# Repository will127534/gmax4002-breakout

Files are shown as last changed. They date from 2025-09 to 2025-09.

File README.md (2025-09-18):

# GMAX4002 breakout board
A basic minimum GMAX4002 (1/1.7" 2048x1200 Global shutter) breakout board for Raspberry Pi



In general this is a simple breakout board for GMAX4002 sensor, see [here](https://github.com/will127534/gmax4002-v4l2-driver) on the driver side of things.
The caveat is that you will need to supply trigger pulses to the TEXP test point in order to trigger a new frame from the sensor and the board will not generate that signal for you, as such this is not really a complete board in my opinion but it might be easier for those who are taking this to integrate in their project.  

_DSC9919  
_DSC0018  
_DSC0022-2  
See the action in video here: [Youtube](https://youtu.be/cdhxaaCYhbM).  
Note that the decoupling capacitor requirements from the leaked pre-released datasheet is a bit... over spec in my opinion(There is no F-way you need 2 x 22uF, 10uF and 100nF for each pixel voltage regulator), the board is deisgned following the datasheet but you can see in the board photos I've omitted some of the capacitors when soldering and it work just fine (I guess).  

At the very least this board has been tested on RPI5 with analog discovery 2 as pulse generating source. Currently I have no plan to continuing develop this board as a raspberry pi camera module but it might be useful for someone looking at this sensor also. Lastly, this project is released as MIT license, do what ever you want with that.

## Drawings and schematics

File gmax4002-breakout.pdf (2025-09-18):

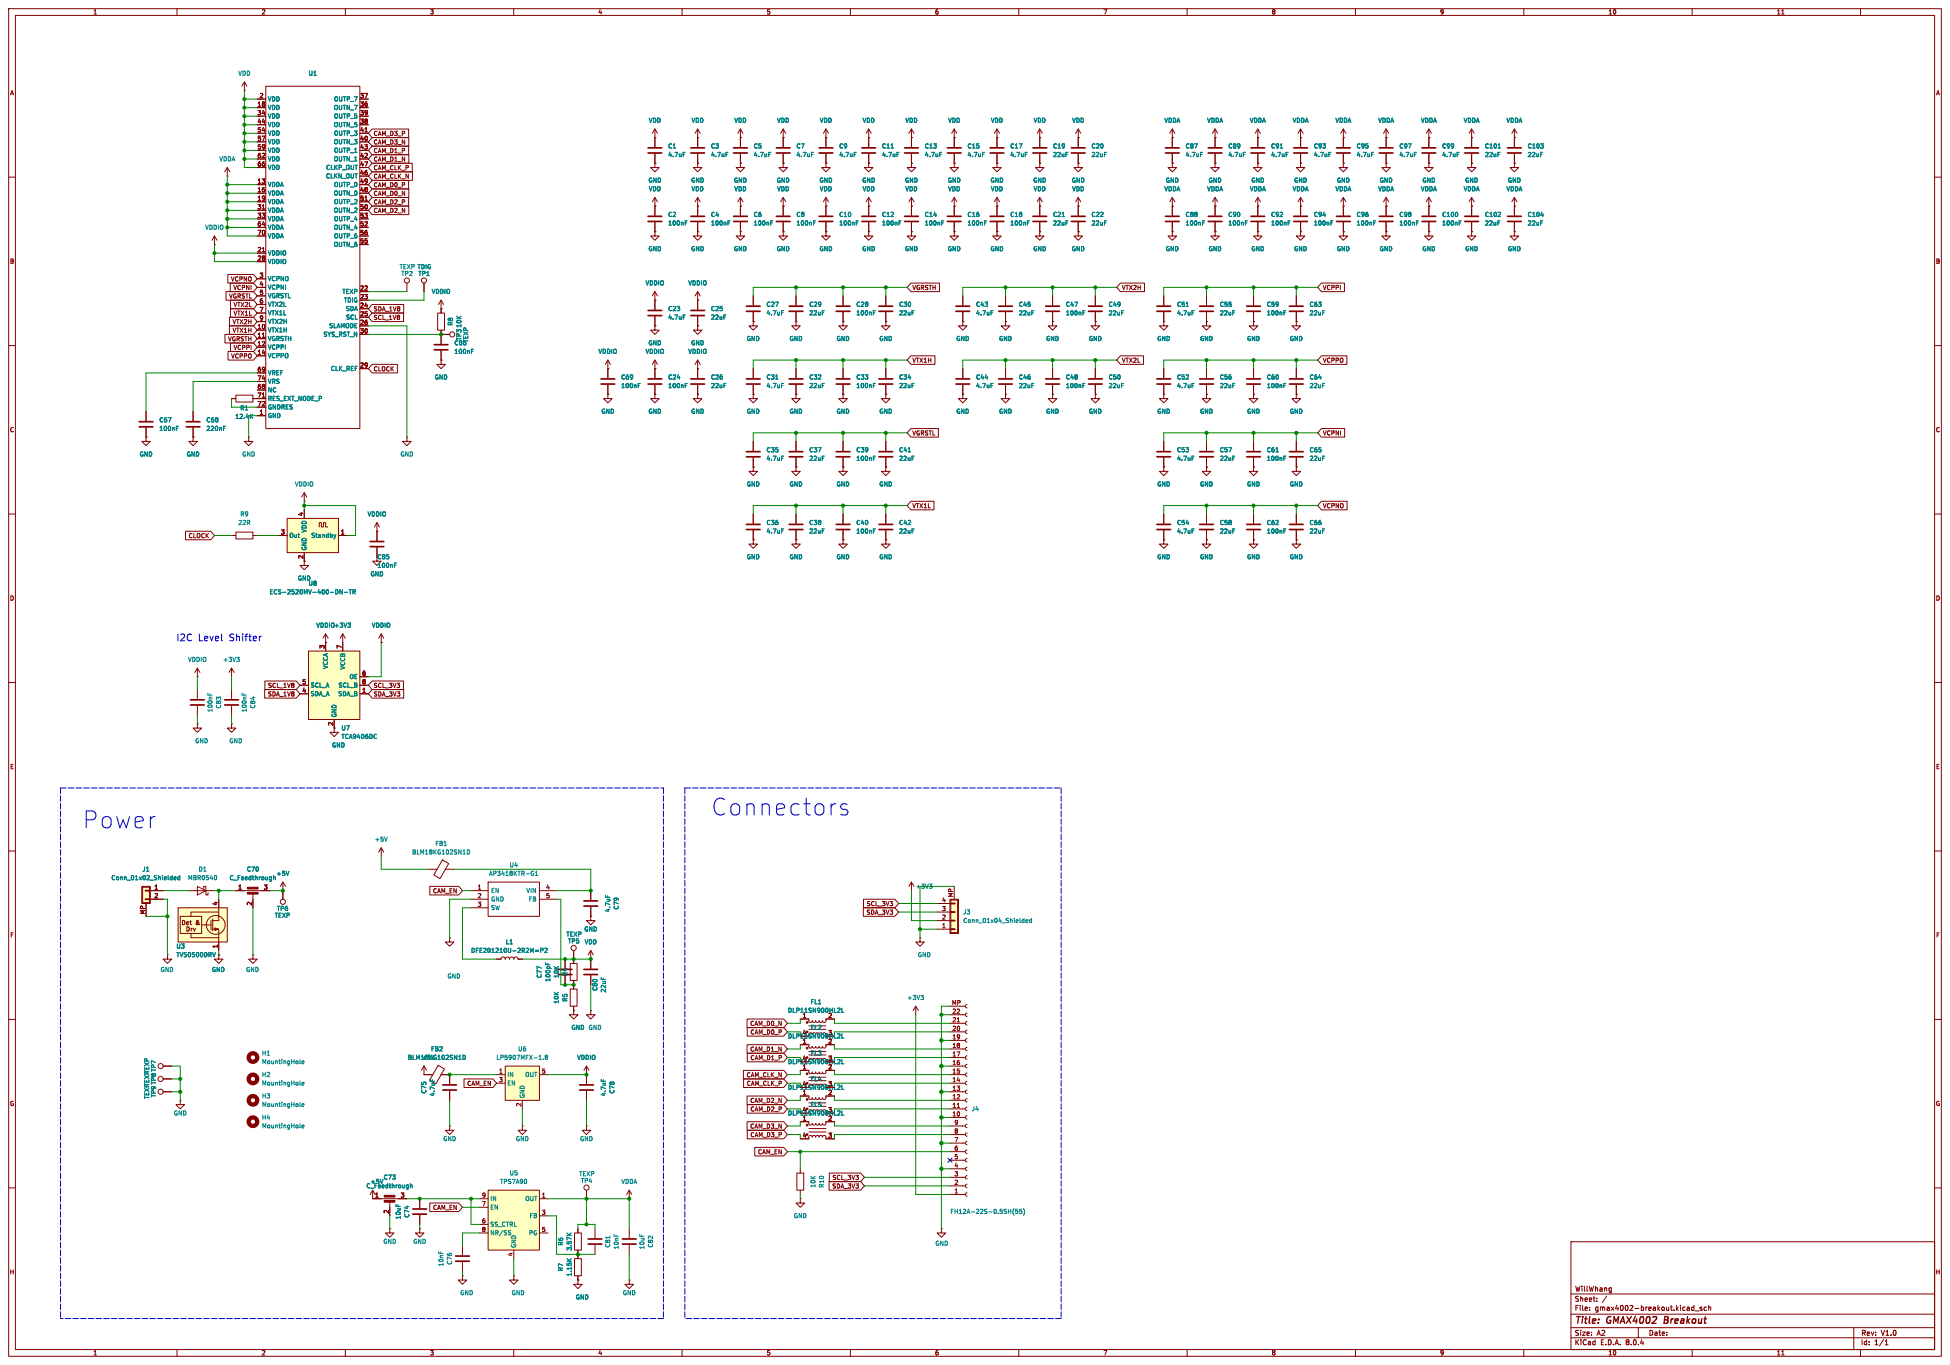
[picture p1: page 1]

4 PG 5 SS_CTRL 6 EN 7 NR/SS 8

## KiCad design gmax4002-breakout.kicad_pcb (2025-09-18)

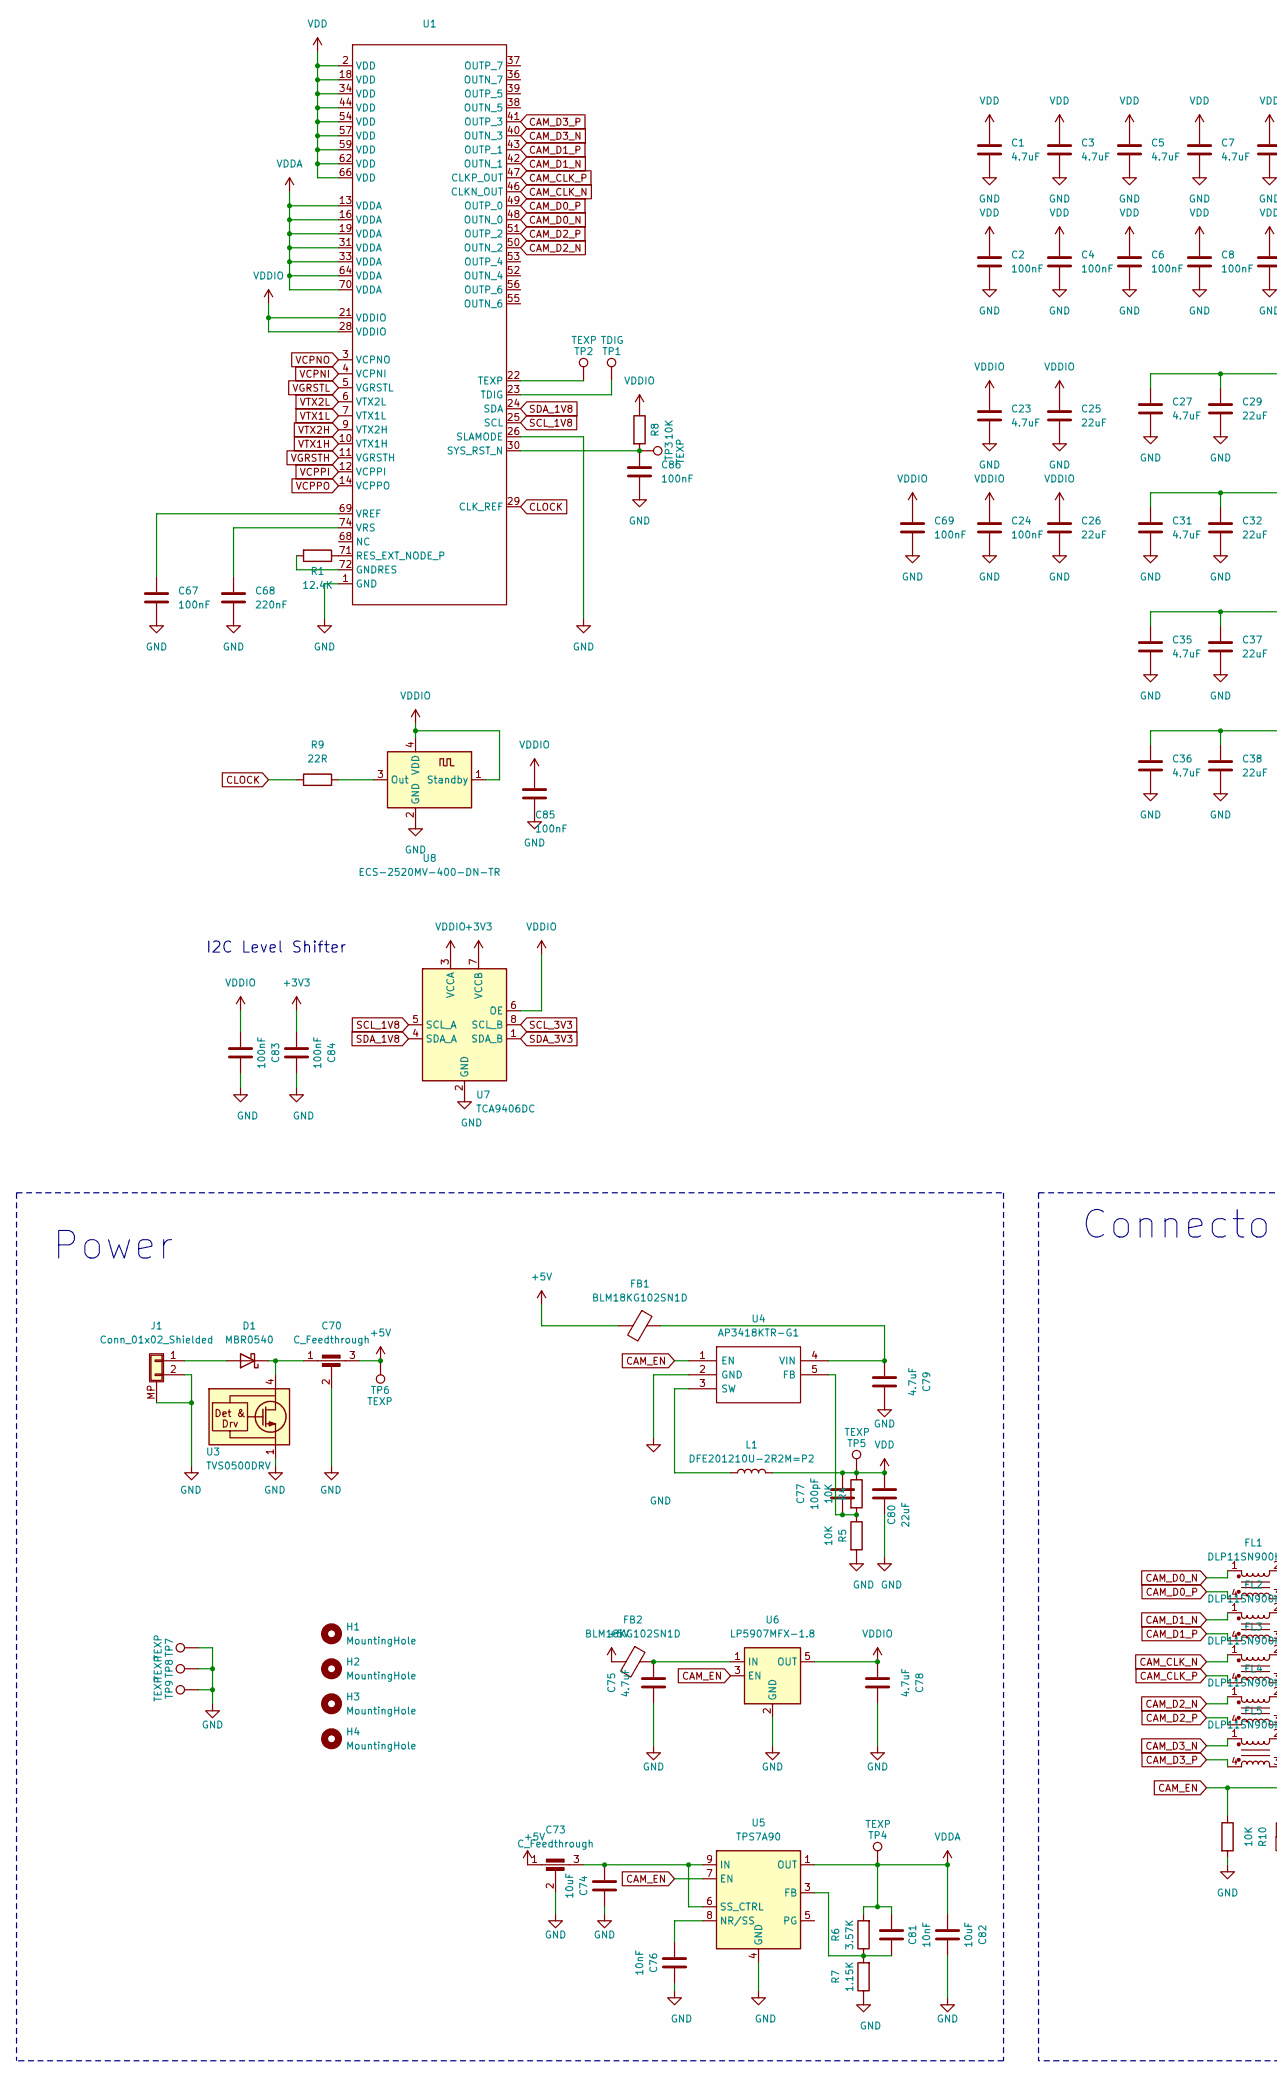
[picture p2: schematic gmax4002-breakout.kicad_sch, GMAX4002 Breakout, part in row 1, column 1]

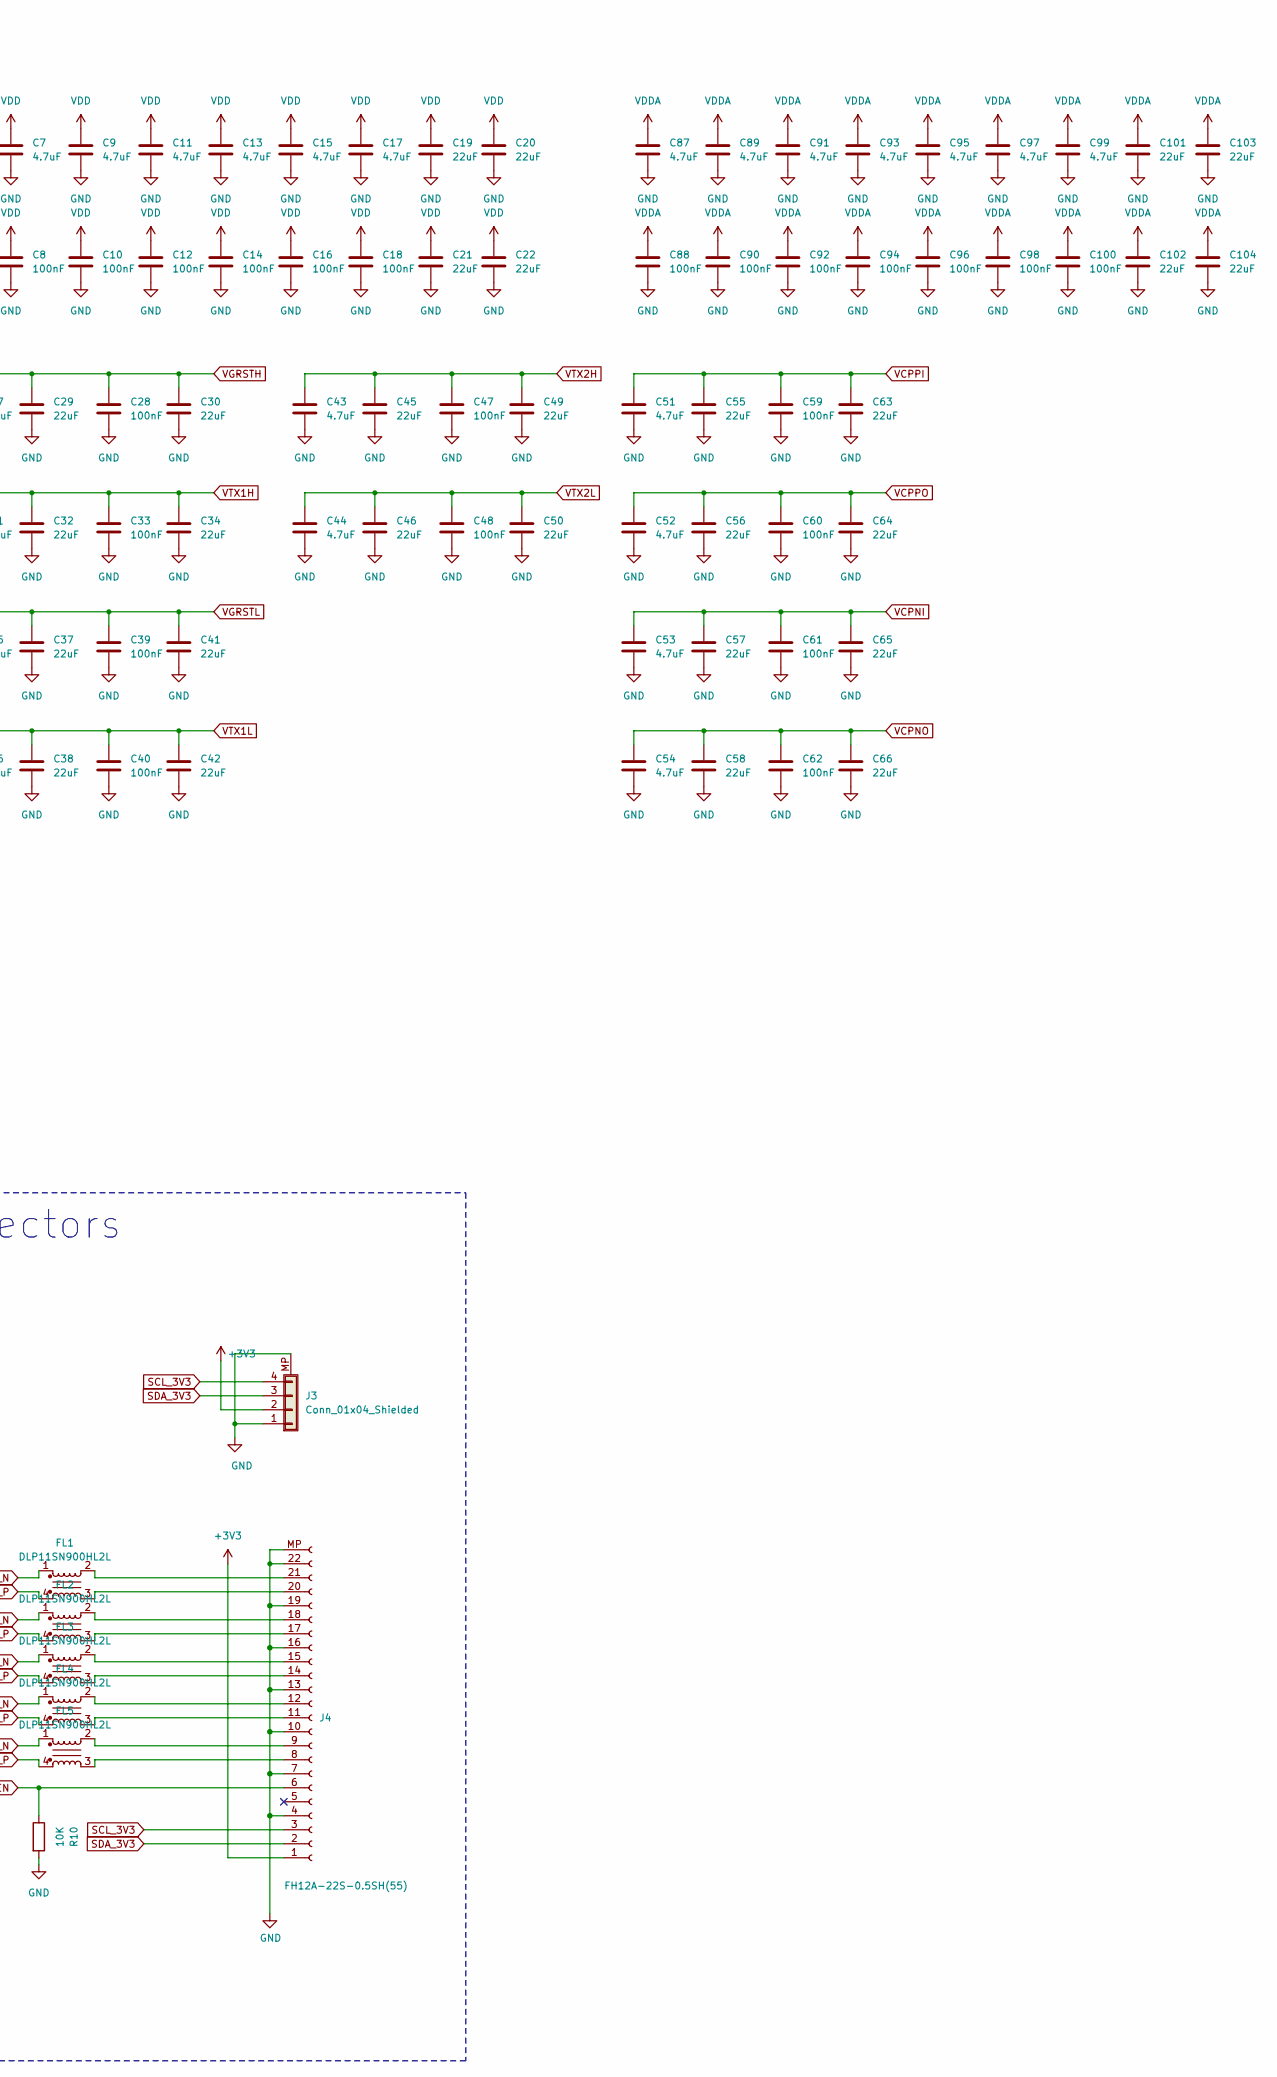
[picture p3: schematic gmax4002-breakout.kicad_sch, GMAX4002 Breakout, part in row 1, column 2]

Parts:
C1, C3, C5, C7, C9, C11, C13, C15, C17, C23, C27, C31, C35, C36, C43, C44, C51, C52, C53, C54, C87, C89, C91, C93, C95, C97, C99: 4.7uF; C_0402_1005Metric
C2, C4, C6, C8, C10, C12, C14, C16, C18, C24, C28, C33, C39, C40, C47, C48, C59, C60, C61, C62, C67, C69, C83, C84, C85, C86, C88, C90, C92, C94, C96, C98, C100: 100nF; C_0402_1005Metric
C19, C20, C21, C22, C25, C26, C101, C102, C103, C104: 22uF; C_0805_2012Metric
C29, C30, C32, C34, C37, C38, C41, C42, C45, C46, C49, C50, C55, C56, C57, C58, C63, C64, C65, C66: 22uF; C_0402_1005Metric
C68: 220nF; C_0402_1005Metric
C70, C73: C_Feedthrough; NFM18CC101R1C3D
C74, C82: 10uF; C_0603_1608Metric
C75, C78, C79: 4.7uF; C_0603_1608Metric
C76, C81: 10nF; C_0402_1005Metric
C77: 100pF; C_0402_1005Metric
C80: 22uF; C_0603_1608Metric
D1: MBR0540; D_SOD-123
FB1, FB2: BLM18KG102SN1D; L_0603_1608Metric
FL1, FL2, FL3, FL4, FL5: DLP11SN900HL2L; DLP11SA350HL2B
H1, H2, H3, H4: MountingHole; MountingHole_2.2mm_M2
J1: Conn_01x02_Shielded; Molex_PicoBlade_53261-0271_1x02-1MP_P1.25mm_Horizontal
J3: Conn_01x04_Shielded; JST_SH_SM04B-SRSS-TB_1x04-1MP_P1.00mm_Horizontal
J4: FH12A-22S-0.5SH(55); Hirose_FH12-22S-0.5SH_1x22-1MP_P0.50mm_Horizontal; Part Description 22 Position FFC, FPC Connector Contacts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
L1: DFE201210U-2R2M=P2; L_0805_2012Metric
R1: 12.4K; R_0402_1005Metric
R4, R5, R8, R10: 10K; R_0402_1005Metric
R6: 3.57K; R_0402_1005Metric
R7: 1.15K; R_0402_1005Metric
R9: 22R; R_0402_1005Metric
TP1: TDIG; TestPoint_Pad_D1.0mm
TP2, TP3, TP4, TP5, TP6, TP7, TP8, TP9: TEXP; TestPoint_Pad_D1.0mm
U1: QFN-74_16.6x12.9_Pitch0.7mm
U3: TVS0500DRV; WSON-6-1EP_2x2mm_P0.65mm_EP1x1.6mm
U4: AP3418KTR-G1; SOT-23-5; Mouser Part Number 621-AP3418KTR-G1
U5: TPS7A90; Texas_S-PDSO-N10_EP1.2x2mm
U6: LP5907MFX-1.8; SOT-23-5
U7: TCA9406DC; TCA9406DCUR
U8: ECS-2520MV-400-DN-TR; Oscillator_SMD_Abracon_ASDMB-4Pin_2.5x2.0mm

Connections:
+3V3: C84.1, J3.2, J4.1, U7.7 (VCCB)
+5V: C70.3, C73.1, FB1.2, FB2.2, TP6.1
CAM_CLK_N: FL3.1, U1.46 (CLKN_OUT)
CAM_CLK_P: FL3.4, U1.47 (CLKP_OUT)
CAM_D0_N: FL1.1, U1.48 (OUTN_0)
CAM_D0_P: FL1.4, U1.49 (OUTP_0)
CAM_D1_N: FL2.1, U1.42 (OUTN_1)
CAM_D1_P: FL2.4, U1.43 (OUTP_1)
CAM_D2_N: FL4.1, U1.50 (OUTN_2)
CAM_D2_P: FL4.4, U1.51 (OUTP_2)
CAM_D3_N: FL5.1, U1.40 (OUTN_3)
CAM_D3_P: FL5.4, U1.41 (OUTP_3)
CAM_EN: J4.6, R10.1, U4.1 (EN), U5.7 (EN), U6.3 (EN)
CLOCK: R9.1, U1.29 (CLK_REF)
GND: C1.2, C2.2, C3.2, C4.2, C5.2, C6.2, C7.2, C8.2, C9.2, C10.2, C11.2, C12.2, C13.2, C14.2, C15.2, C16.2, C17.2, C18.2, C19.2, C20.2, C21.2, C22.2, C23.2, C24.2, C25.2, C26.2, C27.2, C28.2, C29.2, C30.2, C31.2, C32.2, C33.2, C34.2, C35.2, C36.2, C37.2, C38.2, C39.2, C40.2, C41.2, C42.2, C43.2, C44.2, C45.2, C46.2, C47.2, C48.2, C49.2, C50.2, C51.2, C52.2, C53.2, C54.2, C55.2, C56.2, C57.2, C58.2, C59.2, C60.2, C61.2, C62.2, C63.2, C64.2, C65.2, C66.2, C67.2, C68.2, C69.2, C70.2, C73.2, C74.2, C75.1, C76.2, C78.2, C79.2, C80.1, C82.2, C83.2, C84.2, C85.2, C86.2, C87.2, C88.2, C89.2, C90.2, C91.2, C92.2, C93.2, C94.2, C95.2, C96.2, C97.2, C98.2, C99.2, C100.2, C101.2, C102.2, C103.2, C104.2, J1.2, J1.MP (Shield), J3.1, J3.MP (Shield), J4.4, J4.7, J4.10, J4.13, J4.16, J4.19, J4.22, J4.MP, R5.2, R7.1, R10.2, TP7.1, TP8.1, TP9.1, U1.1 (GND), U1.8 (GNDA), U1.15 (GNDA), U1.17 (GND), U1.20 (GND), U1.26 (SLAMODE), U1.27 (GNDA), U1.32 (GNDA), U1.35 (GND), U1.45 (GND), U1.58 (GND), U1.60 (GND), U1.61 (GNDA), U1.63 (GND), U1.65 (GNDA), U1.67 (GND), U1.73 (GNDA), U3.1 (GND), U3.2 (GND), U3.3 (GND), U3.7 (GND), U4.2 (GND), U5.4 (GND), U5.11 (GND), U6.2 (GND), U7.2 (GND), U8.2 (GND)
unnamed: D1.2 (A), J1.1
unnamed: C70.1, D1.1 (K), U3.4 (IN), U3.5 (IN), U3.6 (IN)
unnamed: FL5.3, J4.8
unnamed: FL5.2, J4.9
unnamed: FL4.3, J4.11
unnamed: FL4.2, J4.12
unnamed: FL3.3, J4.14
unnamed: FL3.2, J4.15
unnamed: FL2.3, J4.17
unnamed: FL2.2, J4.18
unnamed: FL1.3, J4.20
unnamed: FL1.2, J4.21
unnamed: R1.2, U1.72 (GNDRES)
unnamed: R1.1, U1.71 (RES_EXT_NODE_P)
unnamed: C86.1, R8.2, TP3.1, U1.30 (SYS_RST_N)
unnamed: TP1.1, U1.23 (TDIG)
unnamed: TP2.1, U1.22 (TEXP)
unnamed: C67.1, U1.69 (VREF)
unnamed: C68.1, U1.74 (VRS)
unnamed: C77.1, R4.2, R5.1, U4.5 (FB)
unnamed: L1.1, U4.3 (SW)
unnamed: C79.1, FB1.1, U4.4 (VIN)
unnamed: C81.1, R6.1, R7.2, U5.3 (FB)
unnamed: C76.1, U5.8 (NR/SS)
unnamed: C73.3, C74.1, U5.6 (SS_CTRL), U5.9 (IN), U5.10 (IN)
unnamed: C75.2, FB2.1, U6.1 (IN)
unnamed: R9.2, U8.3 (Out)
SCL_1V8: U1.25 (SCL), U7.5 (SCL_A)
SCL_3V3: J3.4, J4.3, U7.8 (SCL_B)
SDA_1V8: U1.24 (SDA), U7.4 (SDA_A)
SDA_3V3: J3.3, J4.2, U7.1 (SDA_B)
VCPNI: C53.1, C57.1, C61.1, C65.1, U1.4 (VCPNI)
VCPNO: C54.1, C58.1, C62.1, C66.1, U1.3 (VCPNO)
VCPPI: C51.1, C55.1, C59.1, C63.1, U1.12 (VCPPI)
VCPPO: C52.1, C56.1, C60.1, C64.1, U1.14 (VCPPO)
VDD: C1.1, C2.1, C3.1, C4.1, C5.1, C6.1, C7.1, C8.1, C9.1, C10.1, C11.1, C12.1, C13.1, C14.1, C15.1, C16.1, C17.1, C18.1, C19.1, C20.1, C21.1, C22.1, C77.2, C80.2, L1.2, R4.1, TP5.1, U1.2 (VDD), U1.18 (VDD), U1.34 (VDD), U1.44 (VDD), U1.54 (VDD), U1.57 (VDD), U1.59 (VDD), U1.62 (VDD), U1.66 (VDD)
VDDA: C81.2, C82.1, C87.1, C88.1, C89.1, C90.1, C91.1, C92.1, C93.1, C94.1, C95.1, C96.1, C97.1, C98.1, C99.1, C100.1, C101.1, C102.1, C103.1, C104.1, R6.2, TP4.1, U1.13 (VDDA), U1.16 (VDDA), U1.19 (VDDA), U1.31 (VDDA), U1.33 (VDDA), U1.64 (VDDA), U1.70 (VDDA), U5.1 (OUT), U5.2 (OUT)
VDDIO: C23.1, C24.1, C25.1, C26.1, C69.1, C78.1, C83.1, C85.1, R8.1, U1.21 (VDDIO), U1.28 (VDDIO), U6.5 (OUT), U7.3 (VCCA), U7.6 (OE), U8.1 (Standby), U8.4 (VDD)
VGRSTH: C27.1, C28.1, C29.1, C30.1, U1.11 (VGRSTH)
VGRSTL: C35.1, C37.1, C39.1, C41.1, U1.5 (VGRSTL)
VTX1H: C31.1, C32.1, C33.1, C34.1, U1.10 (VTX1H)
VTX1L: C36.1, C38.1, C40.1, C42.1, U1.7 (VTX1L)
VTX2H: C43.1, C45.1, C47.1, C49.1, U1.9 (VTX2H)
VTX2L: C44.1, C46.1, C48.1, C50.1, U1.6 (VTX2L)

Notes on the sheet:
Connectors
Power
I2C Level Shifter

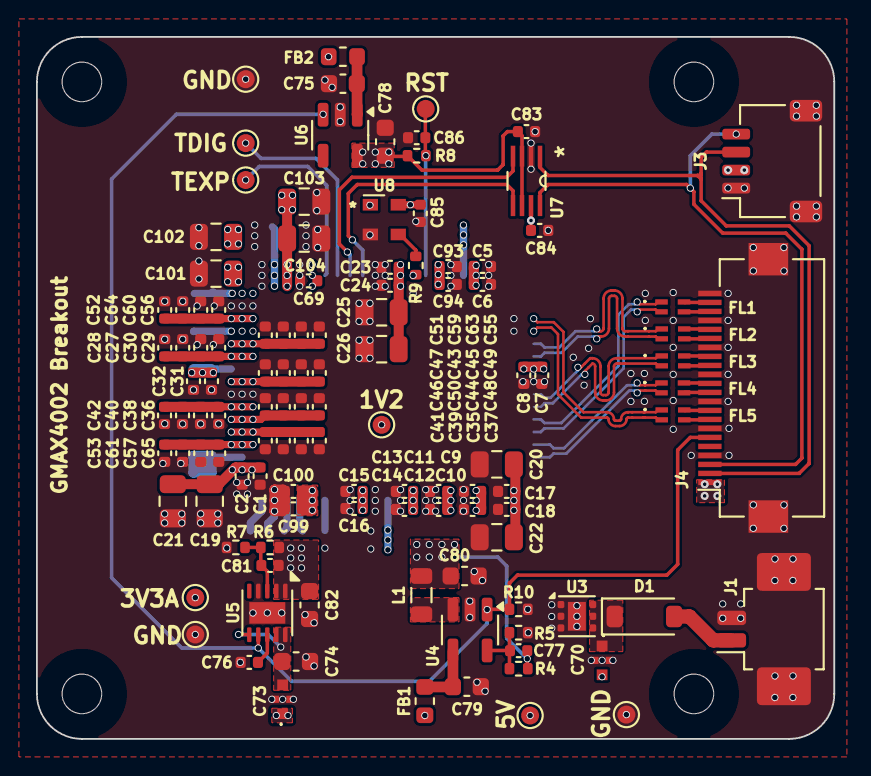
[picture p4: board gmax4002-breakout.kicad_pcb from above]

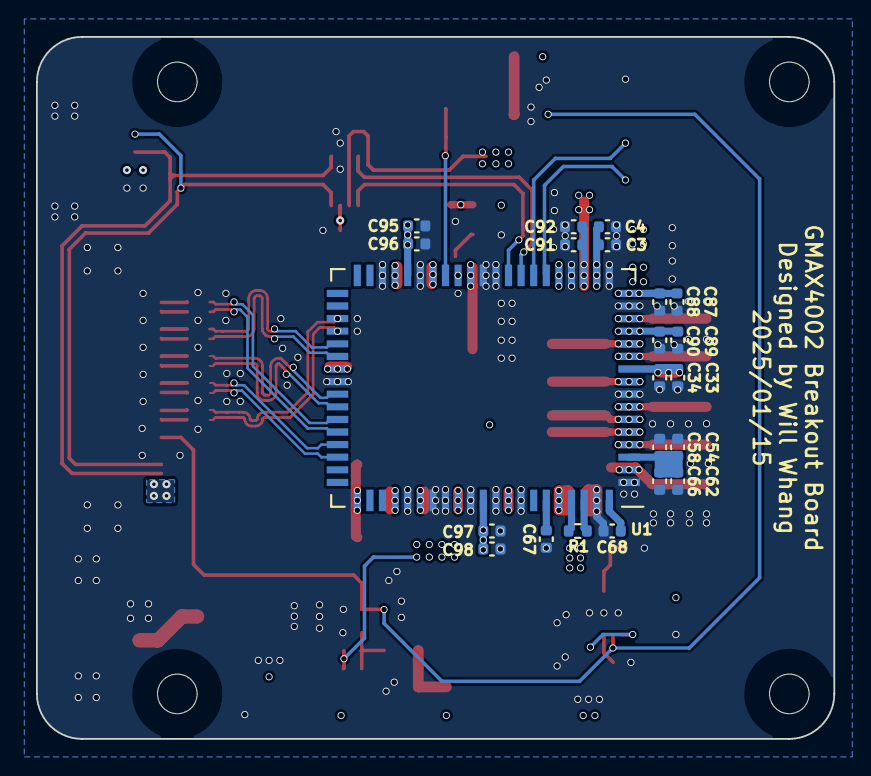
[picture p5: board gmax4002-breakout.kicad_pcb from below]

Board: 4 copper layers, 44.3 x 39.0 mm, 142 parts (22 on the bottom side), 59 nets.
